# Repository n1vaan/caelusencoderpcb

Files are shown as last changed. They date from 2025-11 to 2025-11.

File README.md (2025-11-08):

# Project Caelus Encoder PCB
This is a custom PCB we designed to streamline the control system for our liquid-fueled rocket tests. It combines signal encoding, ignition control, and ESP32-based automation into one board, letting us send multiple control signals through a single ethernet cable and run timed sequences automatically.

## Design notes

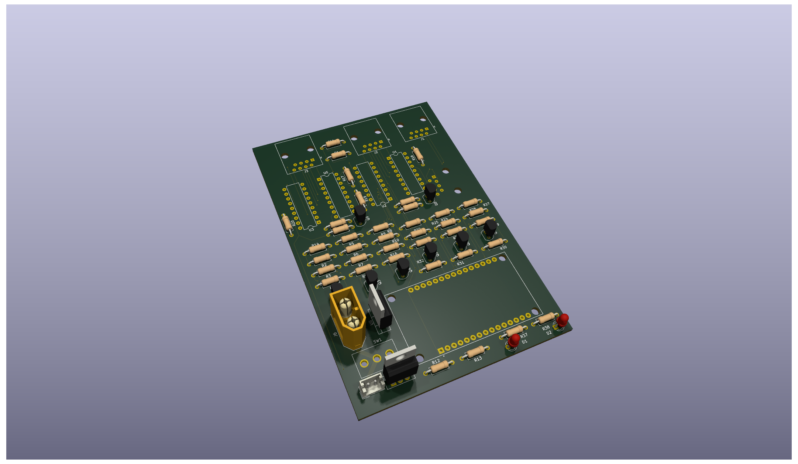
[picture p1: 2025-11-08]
img/Board.png

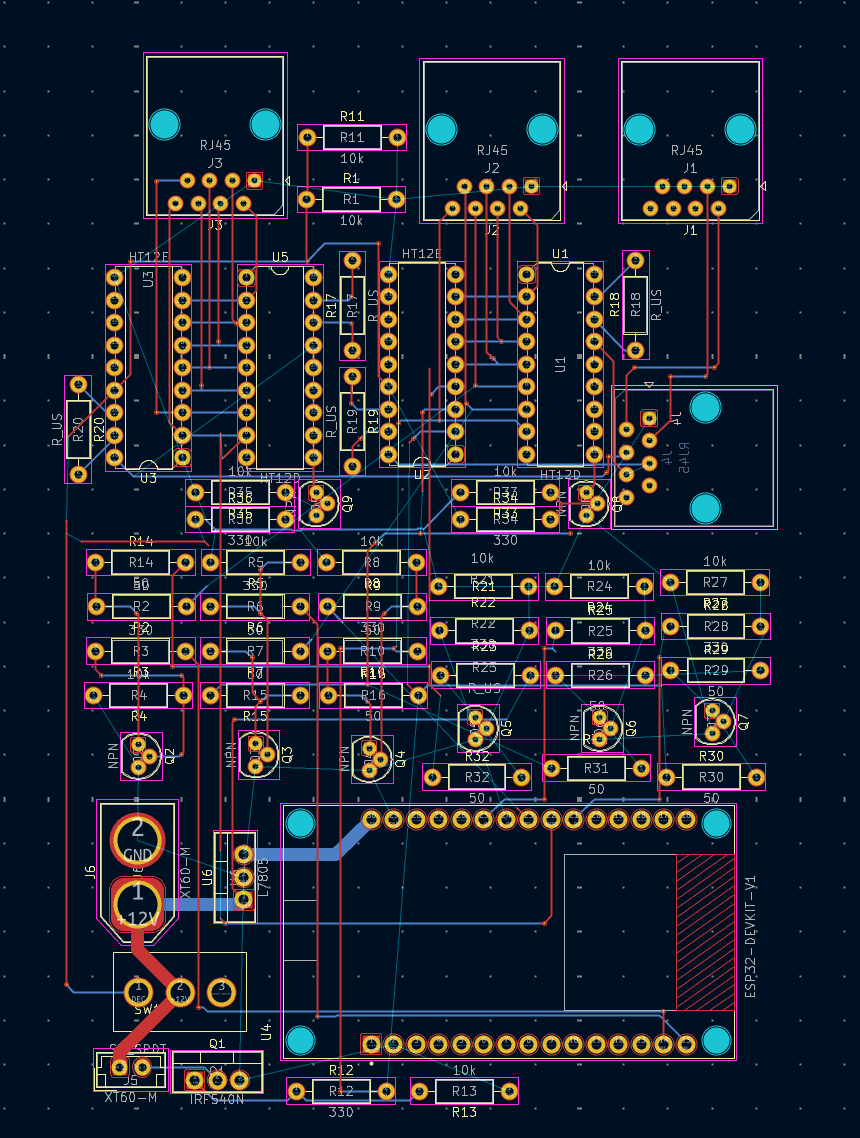
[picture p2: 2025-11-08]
img/Progressimg3.png

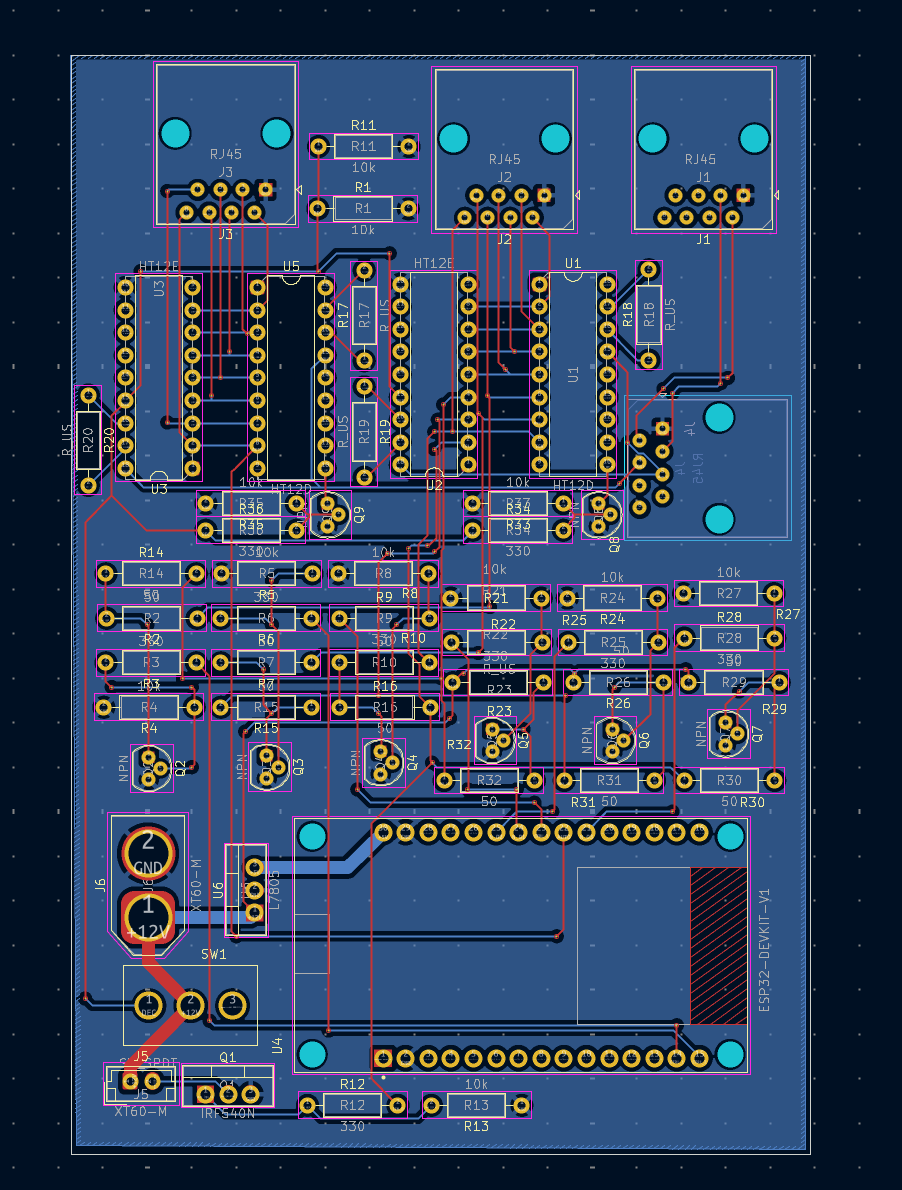
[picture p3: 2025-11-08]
img/Progressimg4.png

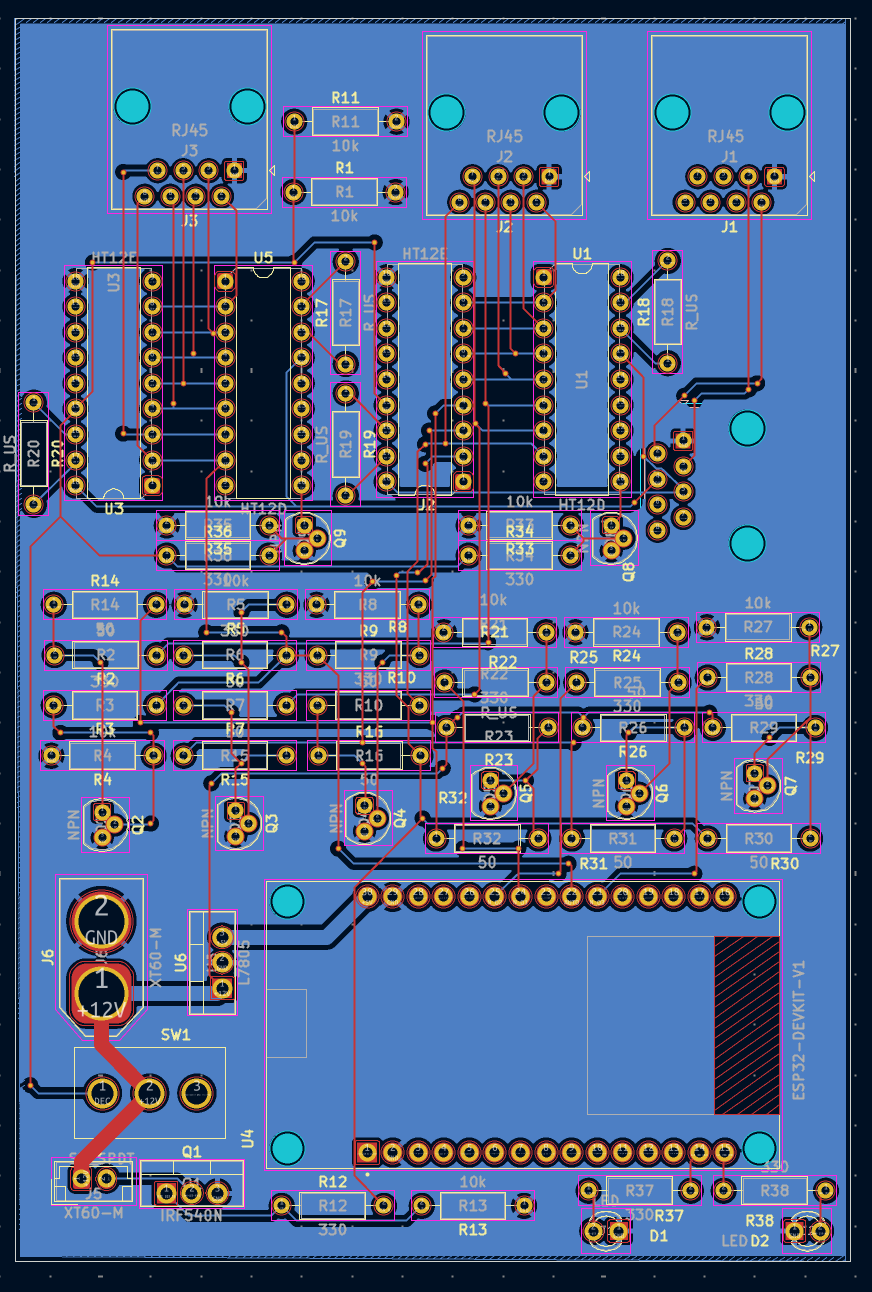
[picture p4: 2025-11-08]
img/PCB.png

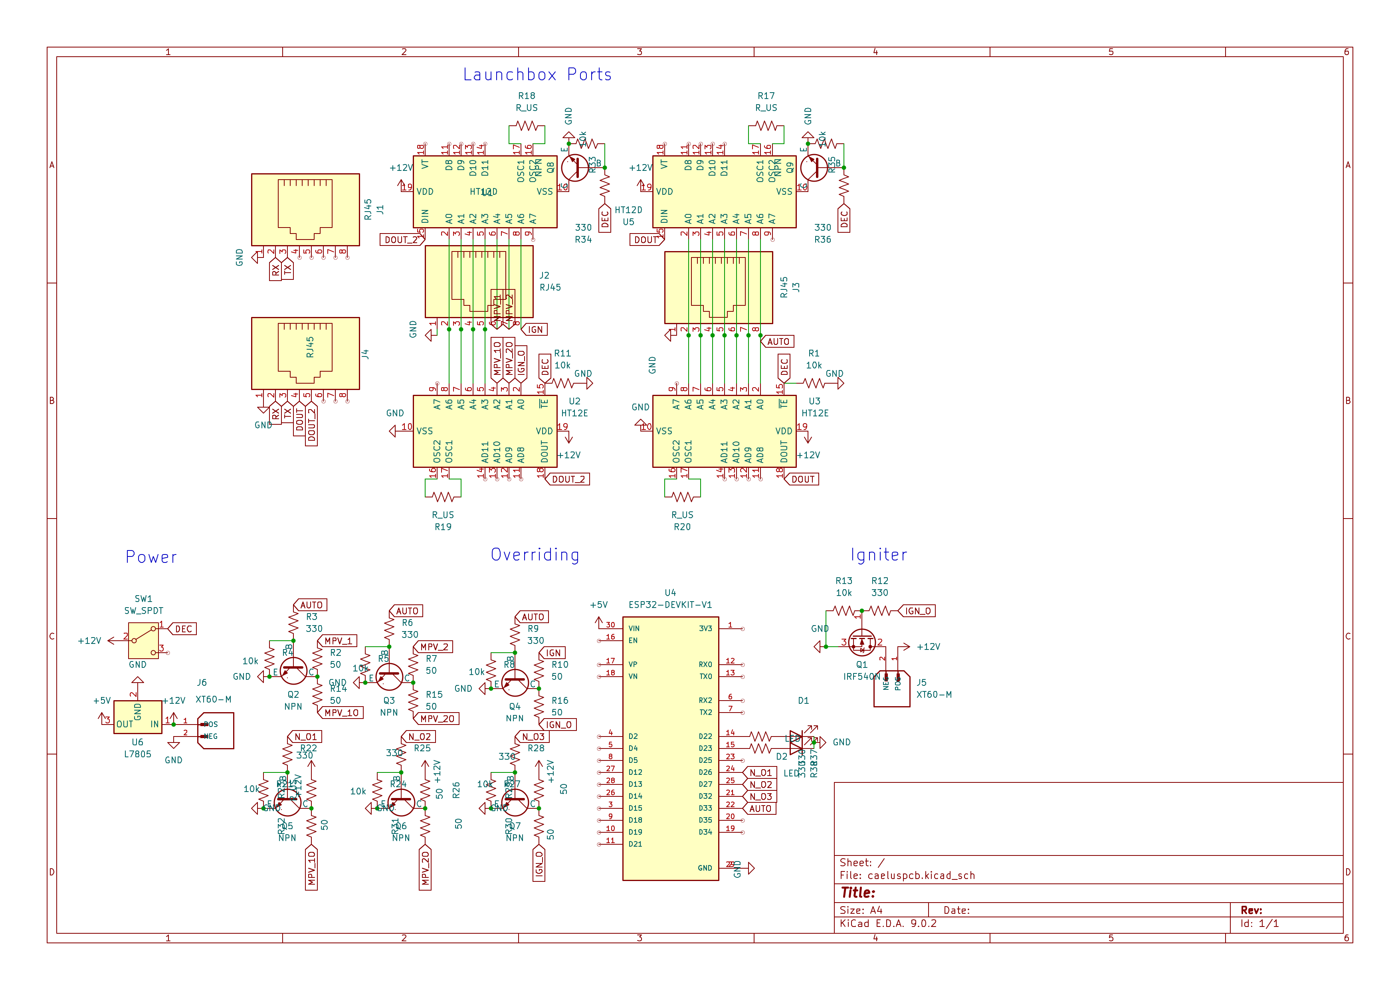
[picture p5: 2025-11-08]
img/Diagram.png

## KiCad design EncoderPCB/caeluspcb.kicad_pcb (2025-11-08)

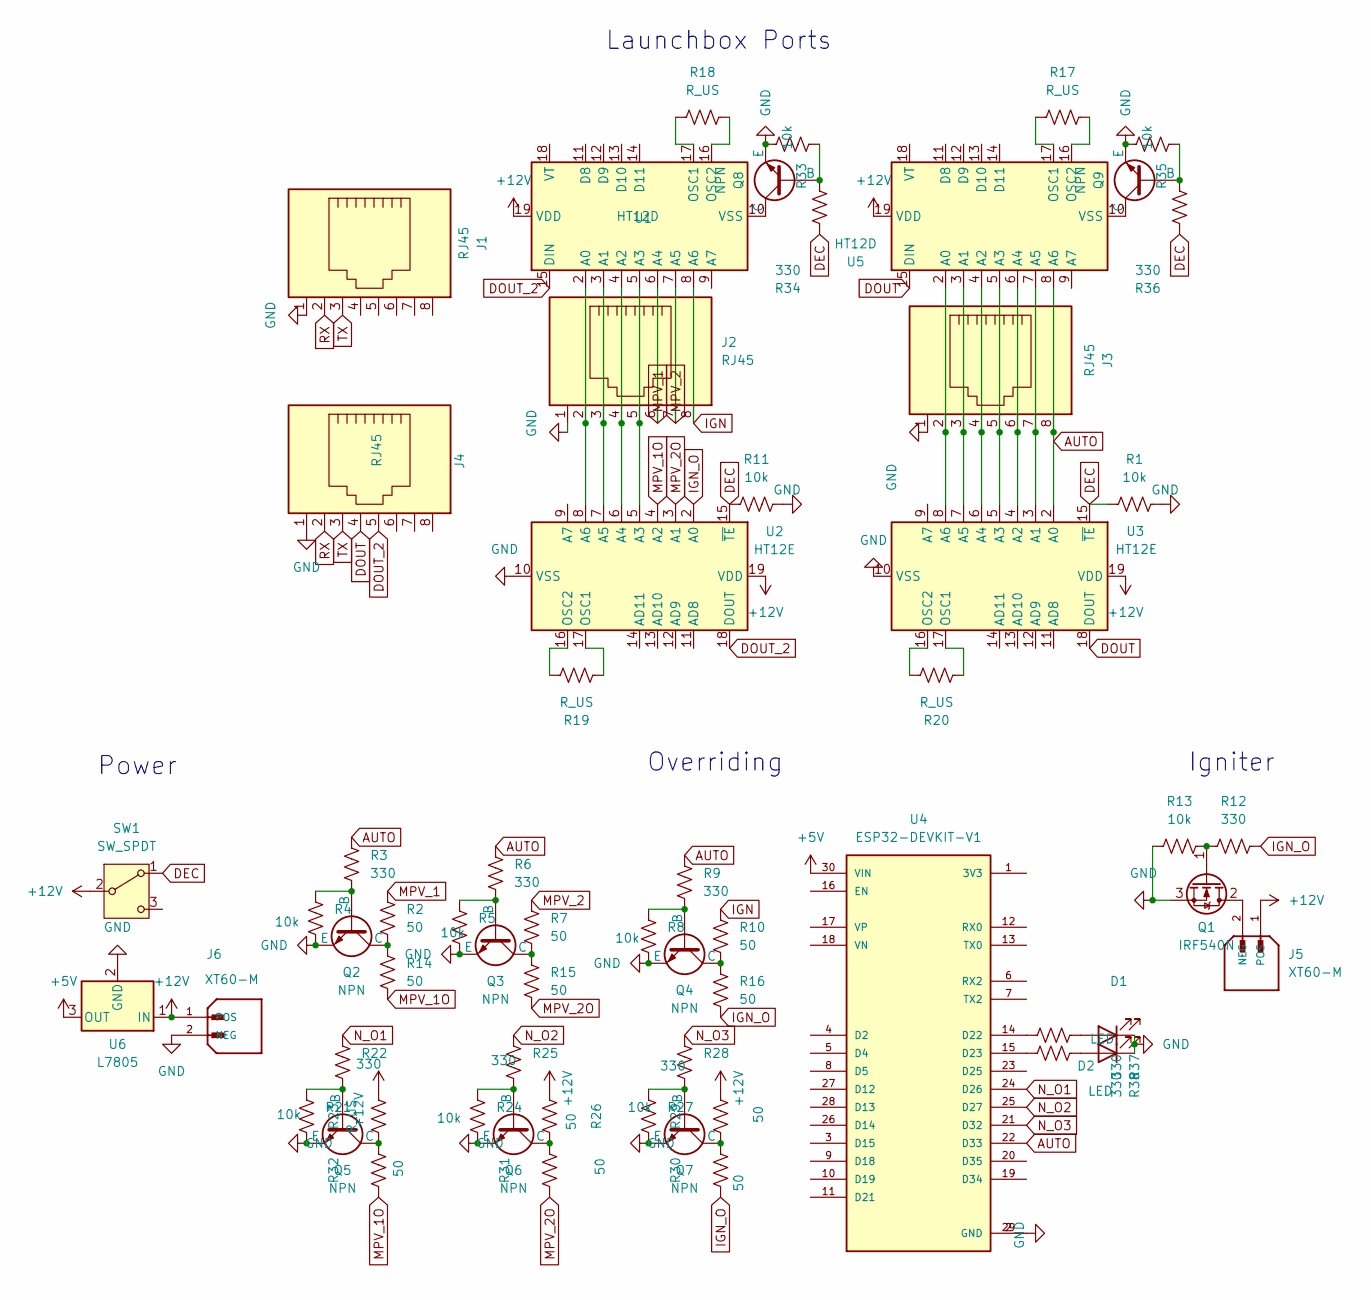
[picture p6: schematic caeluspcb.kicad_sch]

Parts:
D1, D2: LED; LED_D3.0mm
J1, J2, J3, J4: RJ45; RJ45_Amphenol_54602-x08_Horizontal
J5: XT60-M; JST_EH_B2B-EH-A_1x02_P2.50mm_Vertical
J6: XT60-M; AMASS_XT60-M_1x02_P7.20mm_Vertical
Q1: IRF540N; TO-220-3_Vertical
Q2, Q3, Q4, Q5, Q6, Q7, Q8, Q9: NPN; TO-92
R1, R4, R5, R8, R11, R13, R21, R24, R27, R33, R35: 10k; R_Axial_DIN0207_L6.3mm_D2.5mm_P10.16mm_Horizontal
R2, R7, R10, R14, R15, R16, R26, R29, R30, R31, R32: 50; R_Axial_DIN0207_L6.3mm_D2.5mm_P10.16mm_Horizontal
R3, R6, R9, R12, R22, R25, R28, R34, R36, R37, R38: 330; R_Axial_DIN0207_L6.3mm_D2.5mm_P10.16mm_Horizontal
R17, R18, R19, R20, R23: R_US; R_Axial_DIN0207_L6.3mm_D2.5mm_P10.16mm_Horizontal
SW1: SW_SPDT; SPDT_Slide_Switch
U1, U5: HT12D; CERDIP-18_W7.62mm_SideBrazed
U2, U3: HT12E; CERDIP-18_W7.62mm_SideBrazed
U4: ESP32-DEVKIT-V1; MODULE_ESP32_DEVKIT_V1; PARTREV N/A
U6: L7805; TO-220-3_Vertical

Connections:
+5V: U4.30 (VIN), U6.3 (OUT)
+12V: J5.1 (POS), J6.1 (POS), R23.2, R26.2, R29.2, SW1.2 (B), U1.19 (VDD), U2.19 (VDD), U3.19 (VDD), U5.19 (VDD), U6.1 (IN)
AUTO: J3.8, R3.1, R6.1, R9.1, U3.2 (A0), U4.22 (D33), U5.8 (A6)
DEC: R1.1, R11.1, R34.1, R36.1, SW1.1 (A), U2.15 (~TE), U3.15 (~TE)
DOUT: J4.4, U3.18 (DOUT), U5.15 (DIN)
DOUT_2: J4.5, U1.15 (DIN), U2.18 (DOUT)
GND: D1.1 (K), D2.1 (K), J1.1, J2.1, J3.1, J4.1, J6.2 (NEG), Q1.3 (S), Q2.3 (E), Q3.3 (E), Q4.3 (E), Q5.3 (E), Q6.3 (E), Q7.3 (E), Q8.3 (E), Q9.3 (E), R1.2, R4.2, R5.2, R8.2, R11.2, R13.1, R21.2, R24.2, R27.2, R33.2, R35.2, U2.10 (VSS), U3.10 (VSS), U4.2 (GND), U4.29 (GND), U6.2 (GND)
IGN: J2.8, R10.1, U1.8 (A6)
IGN_O: R12.2, R16.2, R30.1, U2.2 (A0)
MPV_1: J2.6, R2.1, U1.6 (A4)
MPV_1O: R14.2, R32.1, U2.4 (A2)
MPV_2: J2.7, R7.1, U1.7 (A5)
MPV_2O: R15.2, R31.1, U2.3 (A1)
N_O1: R22.1, U4.24 (D26)
N_O2: R25.1, U4.25 (D27)
N_O3: R28.1, U4.21 (D32)
unnamed: D1.2 (A), R37.1
unnamed: D2.2 (A), R38.1
unnamed: J5.2 (NEG), Q1.2 (D)
unnamed: Q1.1 (G), R12.1, R13.2
unnamed: Q2.2 (B), R3.2, R4.1
unnamed: Q2.1 (C), R2.2, R14.1
unnamed: Q3.2 (B), R5.1, R6.2
unnamed: Q3.1 (C), R7.2, R15.1
unnamed: Q4.2 (B), R8.1, R9.2
unnamed: Q4.1 (C), R10.2, R16.1
unnamed: Q5.2 (B), R21.1, R22.2
unnamed: Q5.1 (C), R23.1, R32.2
unnamed: Q6.2 (B), R24.1, R25.2
unnamed: Q6.1 (C), R26.1, R31.2
unnamed: Q7.2 (B), R27.1, R28.2
unnamed: Q7.1 (C), R29.1, R30.2
unnamed: Q8.2 (B), R33.1, R34.2
unnamed: Q8.1 (C), U1.10 (VSS)
unnamed: Q9.2 (B), R35.1, R36.2
unnamed: Q9.1 (C), U5.10 (VSS)
unnamed: J2.2, U1.2 (A0), U2.8 (A6)
unnamed: J2.3, U1.3 (A1), U2.7 (A5)
unnamed: J2.4, U1.4 (A2), U2.6 (A4)
unnamed: J2.5, U1.5 (A3), U2.5 (A3)
unnamed: R18.2, U1.17 (OSC1)
unnamed: R18.1, U1.16 (OSC2)
unnamed: R19.2, U2.17 (OSC1)
unnamed: R19.1, U2.16 (OSC2)
unnamed: J3.7, U3.3 (A1), U5.7 (A5)
unnamed: J3.6, U3.4 (A2), U5.6 (A4)
unnamed: J3.5, U3.5 (A3), U5.5 (A3)
unnamed: J3.4, U3.6 (A4), U5.4 (A2)
unnamed: J3.3, U3.7 (A5), U5.3 (A1)
unnamed: J3.2, U3.8 (A6), U5.2 (A0)
unnamed: R20.2, U3.17 (OSC1)
unnamed: R20.1, U3.16 (OSC2)
unnamed: R37.2, U4.14 (D22)
unnamed: R38.2, U4.15 (D23)
unnamed: R17.2, U5.17 (OSC1)
unnamed: R17.1, U5.16 (OSC2)
RX: J1.2, J4.2
TX: J1.3, J4.3

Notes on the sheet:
Power
Igniter
Overriding
Launchbox Ports

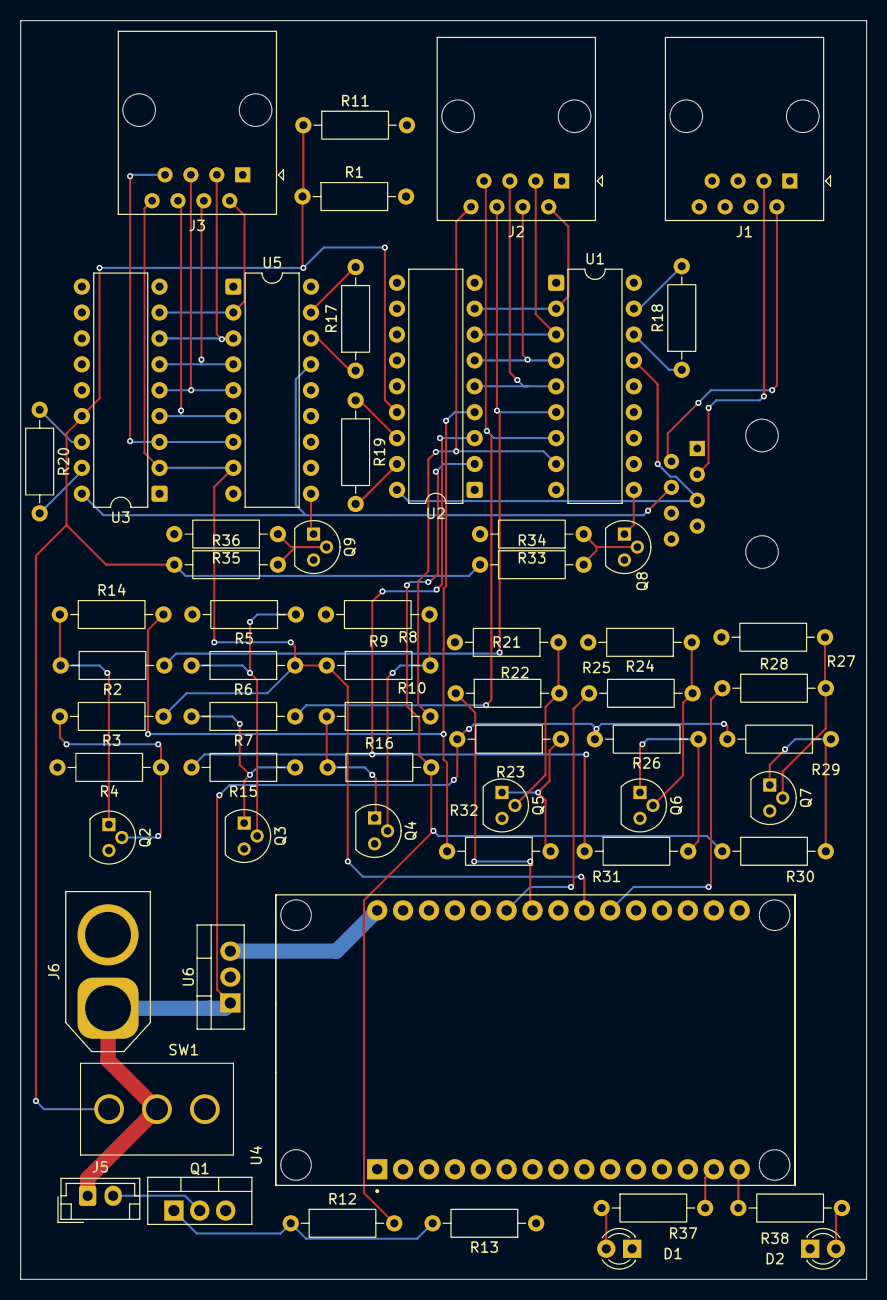
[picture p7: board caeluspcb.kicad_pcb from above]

Board: 2 copper layers, 83.0 x 123.5 mm, 62 parts (1 on the bottom side), 58 nets.

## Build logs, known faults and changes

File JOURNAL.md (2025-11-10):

<!--
  ===================    !!READ THIS NOTICE!!   ====================
  DO NOT edit this file manually. Your changes WILL BE OVERWRITTEN!
  This journal is auto generated and updated by Hack Club Blueprint.
  To edit this file, please edit your journal entries on Blueprint.
  ==================================================================
-->

## 11/8/2025 - Configured layout for PCB  

Today, I finished placing all major components on the custom PCB for our rocket ground control system. This includes the ESP32, RJ45 ports for signal transmission, HT12E/HT12D encoder-decoder chips, NPN transistors for valve/igniter control, and the L7805 voltage regulator. I also added XT60 connectors for power input and set up resistor arrays for signal conditioning. The board layout is organized, but routing and zone fills still need to be done. 

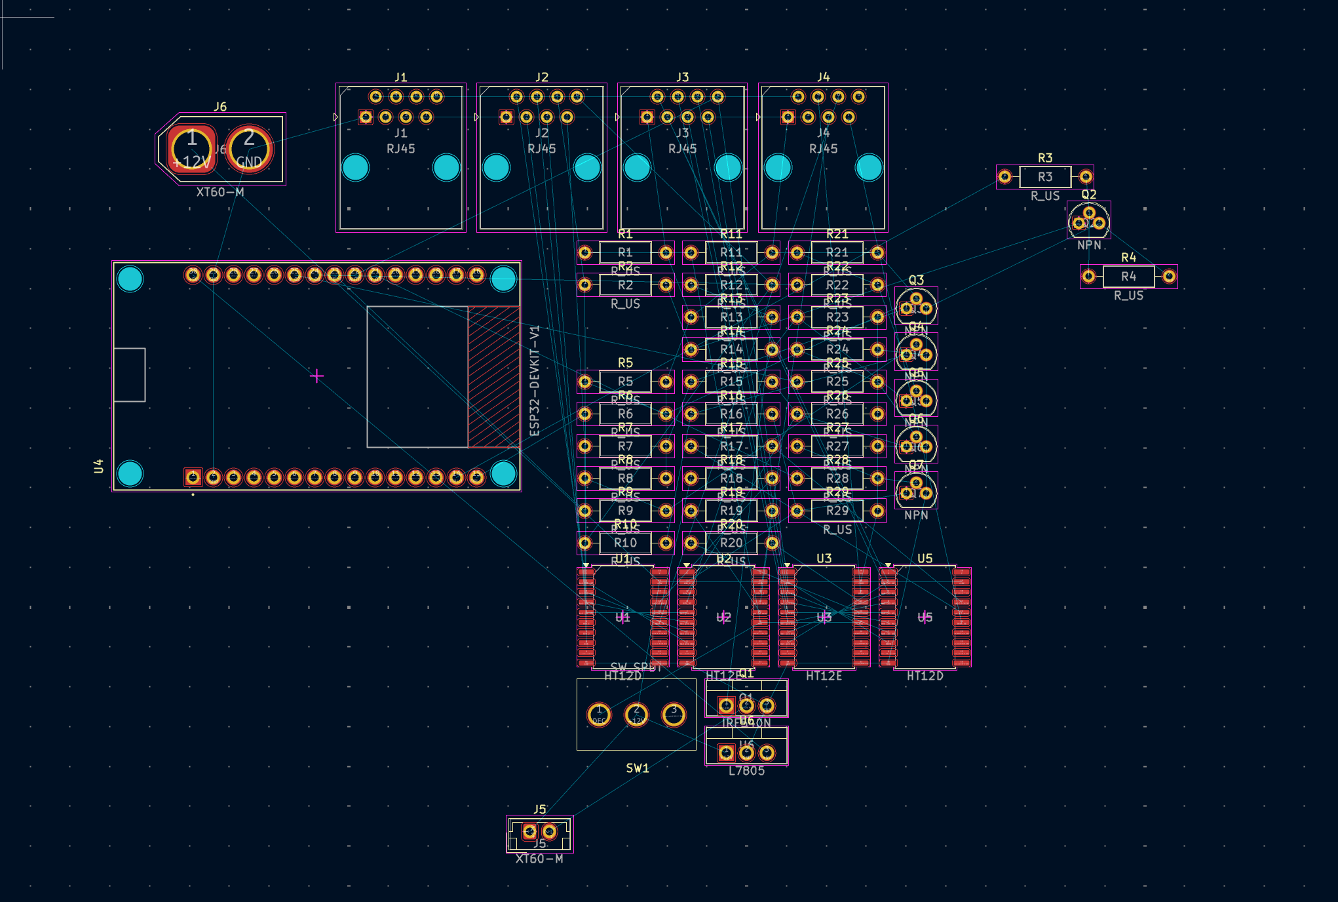
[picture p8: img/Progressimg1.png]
Progess 1 Image


## 11/10/2025 - Signal + Power Routing  

Today, I completed all the signal and power routing on the PCB. All connections between the ESP32, RJ45 ports, HT12E/HT12D chips, transistor drivers, and supporting components are now fully traced. I also finalized placement and routing for the resistor networks and MOSFET power stage. The layout is compact and clean, with minimal via usage and clear signal paths. Next, I’ll focus on ground pours, silkscreen adjustments, and a final DRC pass before generating Gerber files.

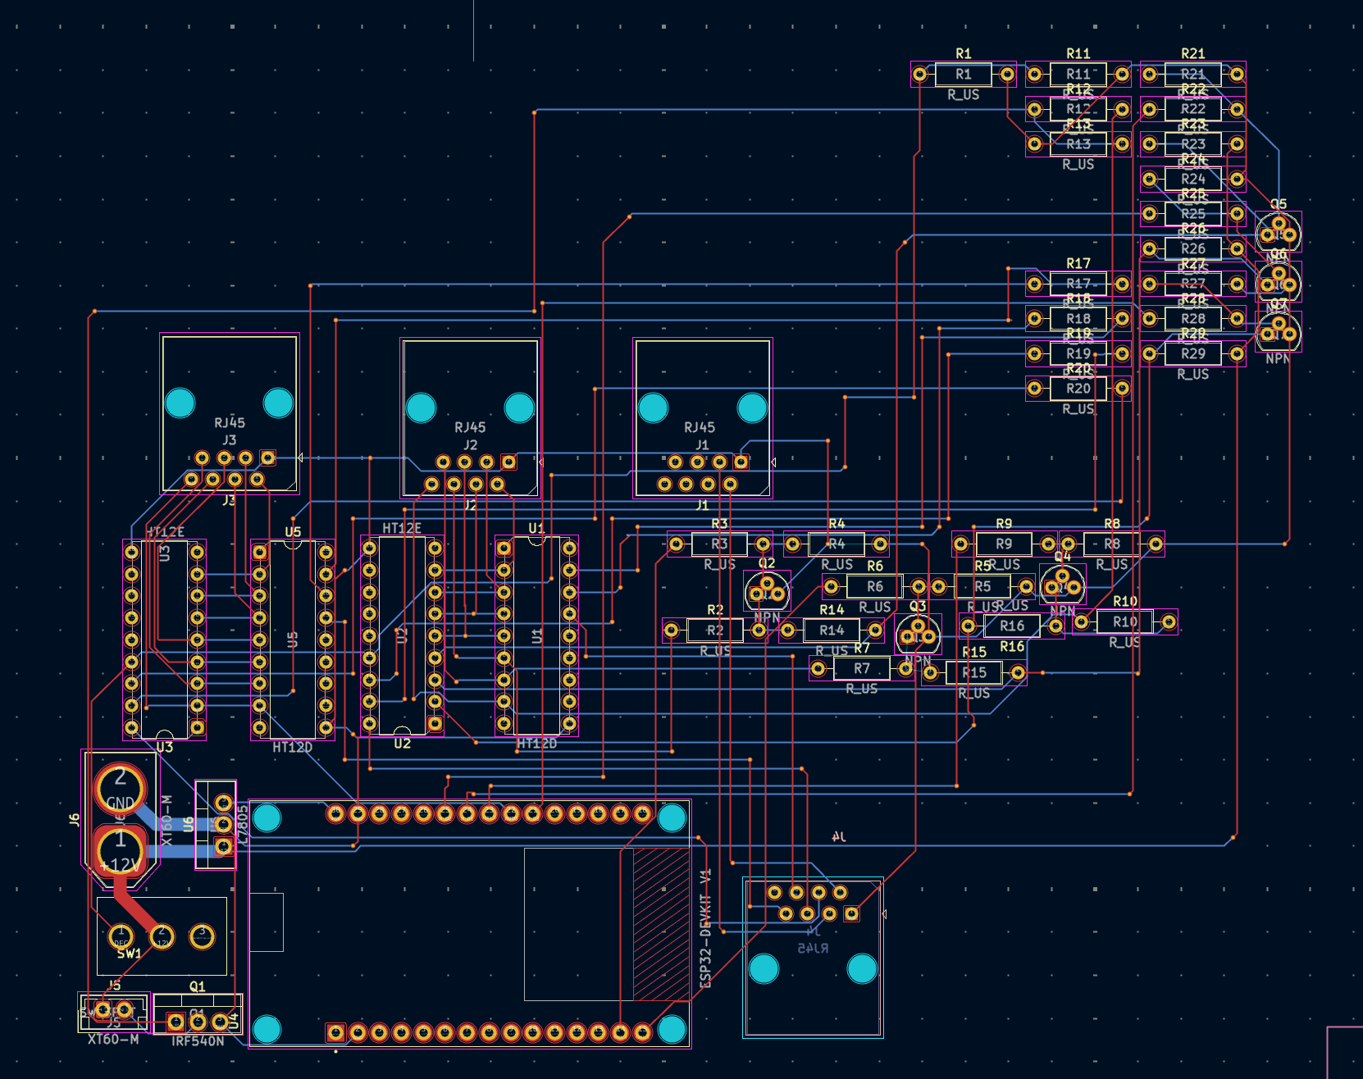
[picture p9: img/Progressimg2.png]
Day 2 Image
